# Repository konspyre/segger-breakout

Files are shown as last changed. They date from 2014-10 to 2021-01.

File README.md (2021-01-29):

# Segger SWD/JTAG Breakout Board



A breakout board for the Segger J-Link (2.54mm pitch) to SWD (1.27mm pitch) headers. Includes silkscreen pinouts for both 2.54mm and 1.27mm pitch connections with mirroring on the opposite sides, and a broken out header area for point-to-point connections.

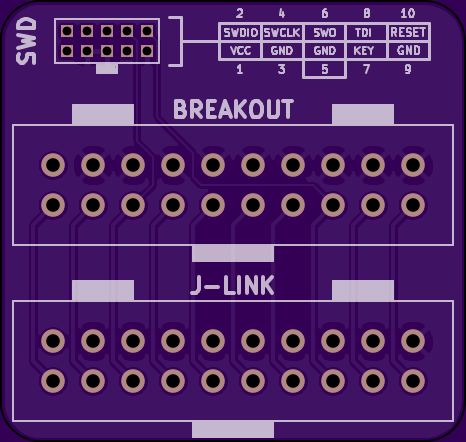
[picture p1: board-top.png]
PCB for the Segger breakbout board, top


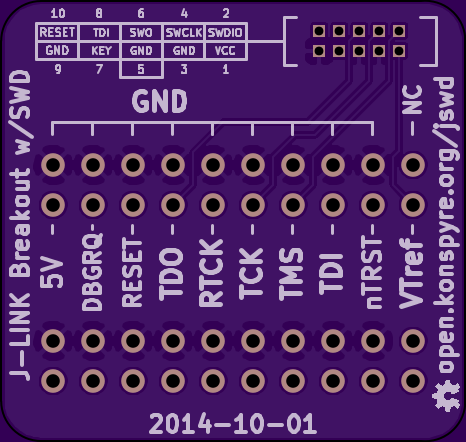
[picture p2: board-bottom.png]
PCB for the Segger breakout board, bottom


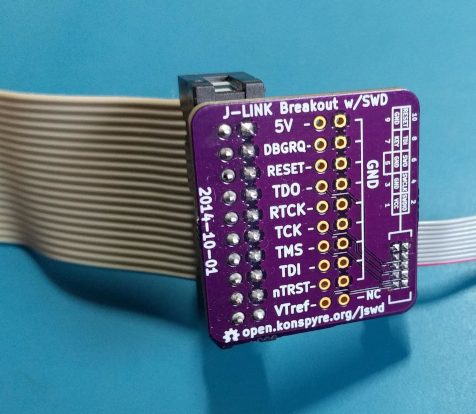
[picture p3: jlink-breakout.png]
PCB assembled with J-Link and SWD cable attached


### Parts

| Quantity | Description | Digikey Part Number |
| - | - | - |
| 1 | 2.54mm header (Segger to board) | [D2520-6002-AR](https://www.digikey.com/products/en?keywords=D2520-6002-AR) | 
| 1 | 1.27mm header  (Board to SWD) | [952-1383-ND](https://www.digikey.com/products/en?keywords=952-1383-ND) |

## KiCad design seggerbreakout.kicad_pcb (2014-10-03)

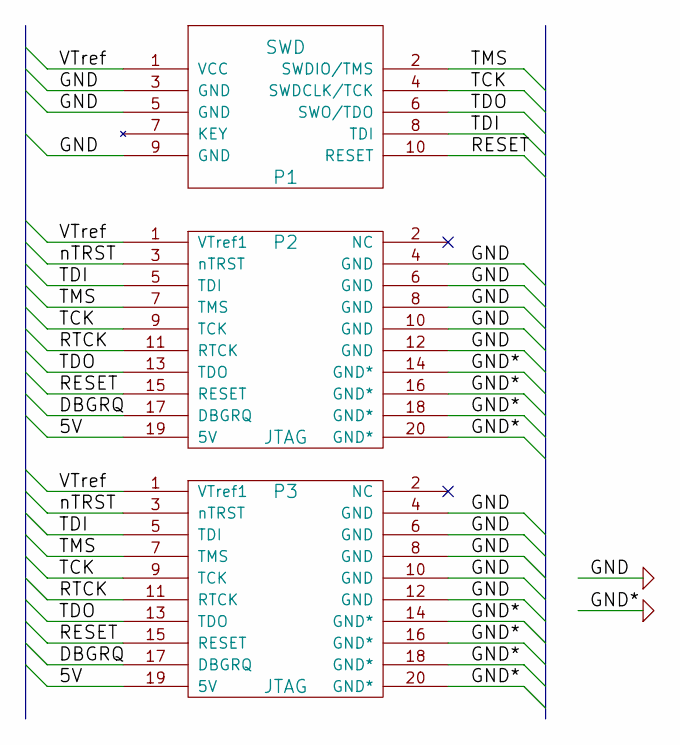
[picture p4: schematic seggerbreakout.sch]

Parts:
P1: SWD
P2, P3: JTAG

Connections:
/5V: P2.19 (5V), P3.19 (5V)
/DBGRQ: P2.17 (DBGRQ), P3.17 (DBGRQ)
/RESET: P1.10 (RESET), P2.15 (RESET), P3.15 (RESET)
/RTCK: P2.11 (RTCK), P3.11 (RTCK)
/TCK: P1.4 (SWDCLK/TCK), P2.9 (TCK), P3.9 (TCK)
/TDI: P1.8 (TDI), P2.5 (TDI), P3.5 (TDI)
/TDO: P1.6 (SWO/TDO), P2.13 (TDO), P3.13 (TDO)
/TMS: P1.2 (SWDIO/TMS), P2.7 (TMS), P3.7 (TMS)
/VTref: P1.1 (VCC), P2.1 (VTref1), P3.1 (VTref1)
/nTRST: P2.3 (nTRST), P3.3 (nTRST)
GND: P1.3 (GND), P1.5 (GND), P1.9 (GND), P2.4 (GND), P2.6 (GND), P2.8 (GND), P2.10 (GND), P2.12 (GND), P2.14 (GND*), P2.16 (GND*), P2.18 (GND*), P2.20 (GND*), P3.4 (GND), P3.6 (GND), P3.8 (GND), P3.10 (GND), P3.12 (GND), P3.14 (GND*), P3.16 (GND*), P3.18 (GND*), P3.20 (GND*)

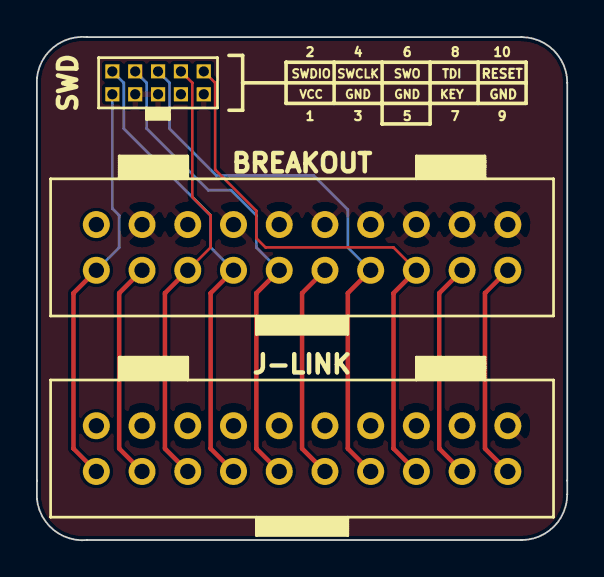
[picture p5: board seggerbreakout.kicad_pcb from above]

Board: 2 copper layers, 29.5 x 28.0 mm, 3 parts (0 on the bottom side), 11 nets.

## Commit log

2014-03-20 Add seggerbreakout, a breakout to the 20P IDC connector the Segger EDU provides
    [seggerbreakout.sch]
2014-03-22 Add footprints
    [seggerbreakout.sch]
2014-04-01 Add swd
    [seggerbreakout.sch]
2014-04-18 Add a breakout portion for jtag connector
    [seggerbreakout.kicad_pcb, seggerbreakout.sch]
2014-06-05 Add segger 20pin connector
    [seggerbreakout.kicad_pcb]
2014-08-18 add swd and 2x5 swd connector
    [seggerbreakout.kicad_pcb, seggerbreakout.sch]
2014-08-18 Add cleaner bus routed version
    [seggerbreakout.sch]
2014-08-18 Sent out for fabrication
    Vendor: OSHPark, LLC
    [seggerbreakout-B_Cu.gbl, seggerbreakout-B_Mask.gbs, seggerbreakout-B_SilkS.gbo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]
2014-08-29 fix hole sizes!
    [seggerbreakout-B_Cu.gbl, seggerbreakout-B_Mask.gbs, seggerbreakout-B_SilkS.gbo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]
2014-08-30 Hole resize and rerouting
    [seggerbreakout.kicad_pcb]
2014-08-31 Sent to fab
    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
    [seggerbreakout-B_Cu.gbl, seggerbreakout-B_Mask.gbs, seggerbreakout-B_SilkS.gbo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]
2014-09-11 Multiple fixes from last fabbed revision
    1. Enlarged annular rings on SWD breakout and made them square, for better solderability
    2. On the last revision, I flipped the large pin headers for ease of use with the SWD connector cable,
    however I neglected to also flip the silkscreen indicators as well. This has been fixed.
    3. Corrected the silkscreen for the large pin headers, they were a bit larger than the actual keyed tabs.
    Parts:
    20P header: D2520-6002-AR - Vendor: Mouser
    SWD header (open, non-keyed): 952-1383-ND - Vendor: Digikey
    [seggerbreakout.kicad_pcb]
2014-09-11 Update fill zones
    [seggerbreakout.kicad_pcb]
2014-09-12 Update tracks and routing to be cleaner and submit to fabrication
    Board vendor: OSHPark, LLC
    Board date: 2014-09-12
2014-09-12 Add final version sent to fab
    [seggerbreakout.kicad_pcb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]
2014-09-30 Improve thermals for PTH->ground plane connections
    [seggerbreakout.kicad_pcb]
2014-10-01 Add a SWD guide (incorrect for now due to upside down reading of segger docs)
    [seggerbreakout.kicad_pcb]
2014-10-02 Correct SWD pinout on schematic and footprint
    [seggerbreakout.sch]
2014-10-02 Update SWD pinout guide and correct schematics to be proper
    [seggerbreakout.kicad_pcb]
2014-10-03 Add front-side silkscreen for segger breakout
    [seggerbreakout.kicad_pcb]
2014-10-03 Re-route TDO trace (it wrapped around before)
    [seggerbreakout.kicad_pcb]
2014-10-03 Production gerbers, board date 10-1-2014
    Fabricator: OSHPark, LLC
    [seggerbreakout-B_Cu.gbl, seggerbreakout-B_Mask.gbs, seggerbreakout-B_SilkS.gbo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]
2019-03-11 Add board pictures and documentation
2019-03-11 Add .gitignore for KiCAD
2021-01-29 J-Link: Add image of board
